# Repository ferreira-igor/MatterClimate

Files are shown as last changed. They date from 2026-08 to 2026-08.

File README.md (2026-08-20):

# MatterClimate






This project transforms an ESP32-based board into a Matter-compatible temperature and humidity sensor using an SHT30 sensor. It provides seamless integration with smart home ecosystems like Alexa, Google Home, and Apple Home through the Matter protocol.

Designed for smart home enthusiasts and developers, this device automatically detects and commissions itself into your Matter network, providing real-time temperature and humidity readings without complex configuration.

The system features automatic commissioning method selection (BLE or WiFi), persistent Matter configuration, robust error recovery with automatic reboot, and LED status indication for easy setup.

## Features

- **Matter Protocol Support**: Compatible with Matter-certified smart home hubs (Alexa, Google Home, Apple Home)
- **Environmental Sensing**: Accurate temperature and humidity readings with SHT30 sensor
- **Automatic Commissioning**: Smart method selection based on hardware capabilities
  - **BLE Commissioning** (ESP32-C3): Standard Matter commissioning via BLE - WiFi credentials provided by the commissioner app
  - **WiFi Commissioning** (Fallback): Captive portal for manual WiFi configuration when BLE is unavailable
- **Smart Reporting**: Configurable thresholds (0.3°C temperature, 2.0% humidity) to minimize network traffic
- **Automatic Recovery**: Detects and handles Matter disconnections, reboots after 60 seconds of lost connectivity
- **LED Status Indication**: Clear visual feedback - LED ON means ready for commissioning, LED OFF means commissioned
- **Automatic Reconnection**: WiFi watchdog for reliable connectivity
- **Error Handling**: Graceful failure recovery with automatic restarts

## Hardware

### Required Components

- ESP32 Development Board (Tested on WeAct Studio ESP32C3, compatible with most ESP32 boards)
- SHT30 Temperature and Humidity Sensor (I2C address 0x45)
- USB Cable for programming and power
- Connecting wires (4-pin I2C connection)

### Supported Boards

The code is tested on the WeAct Studio ESP32C3 but should work on any ESP32-based board with the following:
- Built-in LED (configurable via LED_BUILTIN)
- I2C pins (configurable via pin_i2c_scl and pin_i2c_sda)
- BLE support (for automatic commissioning) or fallback to WiFi commissioning

### Sensor Compatibility

The SHT30 sensor is recommended and tested. Other I2C temperature/humidity sensors may work with minor code modifications:
- SHT31 (compatible)
- SHT35 (compatible)
- AHT10/AHT20 (would require code changes)

## Wiring

The project requires minimal wiring - just the I2C connection for the sensor:

| Component | ESP32 Pin | Description |
|---|---|---|
| SHT30 VCC | 3.3V | Power supply |
| SHT30 GND | GND | Ground |
| SHT30 SCL | GPIO 0 | I2C Clock (WeAct Studio ESP32C3) |
| SHT30 SDA | GPIO 1 | I2C Data (WeAct Studio ESP32C3) |
| Built-in LED | LED_BUILTIN | Status indicator (active LOW) |

**Note**: For other ESP32 boards, adjust the I2C pins in the code:
- pin_i2c_scl: Change to your SCL pin (default: 0)
- pin_i2c_sda: Change to your SDA pin (default: 1)

## Flashing

### Method 1: Pre-compiled Binary

1. Download the latest binary from the Releases page

2. Install esptool:
   ```bash
   pipx install esptool
   ```

3. Using esptool:
   ```bash
   esptool --port /dev/ttyUSB0 erase-flash
   esptool --port /dev/ttyUSB0 write-flash 0x0 MatterClimate.ino.merged.bin
   ```

   Replace /dev/ttyUSB0 with your actual serial port.

### Method 2: Using Arduino IDE

1. **Install ESP32 Core**:
   - Open Arduino IDE
   - Go to File > Preferences
   - Add https://raw.githubusercontent.com/espressif/arduino-esp32/gh-pages/package_esp32_index.json to Additional Boards Manager URLs
   - Go to Tools > Board > Boards Manager
   - Search for ESP32 and install esp32 by Espressif Systems (v3.3.11 or later)

2. **Install Required Libraries**:
   - Open Sketch > Include Library > Manage Libraries
   - Install the following libraries:
     - Adafruit SHT31 by Adafruit (v2.2.2)
     - Matter by Arduino (v1.2.5 or later)
     - WiFiManager by tzapu (v2.0.17) - only required when BLE commissioning is disabled

3. **Configure and Upload**:
   - Open MatterClimate.ino in Arduino IDE
   - Select your ESP32 board: Tools > Board > ESP32 Arduino > [Your Board Model]
   - Select the correct port: Tools > Port > [Your USB Port]
   - Select "Erase All Flash Before Sketch Upload: Enabled"
   - Select "Partition Scheme: Huge APP (3MB No OTA/1MB SPIFFS)"
   - Click Upload (arrow icon) to compile and flash

4. **Monitor Serial Output**:
   - Open Tools > Serial Monitor
   - Set baud rate to 115200
   - Observe startup logs and sensor readings

## Startup

### First Boot and Commissioning

The commissioning method depends on your ESP32 board and the CONFIG_ENABLE_CHIPOBLE flag:

#### Method 1: BLE Commissioning (Recommended - ESP32-C3)

1. **Power the Device**: Connect the ESP32 via USB or power supply
2. **LED Behavior**:
   - LED ON (LOW): Device is NOT commissioned - ready for setup
   - LED OFF (HIGH): Device IS commissioned - operating normally
3. **Commission via Smart Home App**:
   - Open your Matter-compatible app (Alexa, Google Home, Apple Home)
   - Add a new device and scan the QR code displayed in the serial monitor
   - Or enter the manual pairing code shown in the serial output
   - The app will provide WiFi credentials via BLE
   - Wait for commissioning to complete
   - The LED will turn OFF (HIGH) once commissioned

#### Method 2: WiFi Commissioning (Fallback - no BLE)

1. **Power the Device**: Connect the ESP32 via USB or power supply
2. **Connect to Captive Portal**:
   - The device creates a WiFi access point (usually named MatterClimate or similar)
   - Connect your phone or computer to this network
3. **Configure WiFi**:
   - Open a web browser and navigate to the captive portal (usually 192.168.4.1)
   - Enter your WiFi credentials
   - Device will connect to your WiFi network
4. **Commission via Matter**:
   - Use your Matter-compatible app to add the device
   - Scan the QR code or enter the manual pairing code shown in the serial monitor
   - The device will be commissioned to your Matter hub

### Commissioning Information

After startup, the serial monitor will display:
- Manual pairing code (numeric code for manual entry)
- QR code URL (for scanning with smart home apps)

Use this information to commission the device to your Matter hub.

### LED Status Indicator

| LED State | Pin State | Meaning |
|---|---|---|
| ON (LOW) | 0 | Device NOT commissioned - ready for setup |
| OFF (HIGH) | 1 | Device IS commissioned - operating normally |

## Configuration

### Sensor Reporting Thresholds

The device uses smart reporting to minimize network traffic:

- **Temperature**: Reports when changes exceed 0.3°C
- **Humidity**: Reports when changes exceed 2.0%

These thresholds can be adjusted in the code:
- temperature_diff: Adjust as needed (default: 0.3f)
- humidity_diff: Adjust as needed (default: 2.0f)

### Timing Parameters

| Parameter | Default | Description |
|---|---|---|
| Sensors Read Interval | 1 second | How often sensor is read |
| Matter Check Interval | 15 seconds | How often connection is verified |
| Matter Timeout | 3 minutes | Max disconnection time before reboot |
| WiFi Manager Timeout | 3 minutes | Captive portal timeout (WiFi method) |

## Notes

### Important Considerations

- **Matter Compatibility**: Ensure your smart home hub supports Matter (most modern hubs do)
- **Network Requirements**: Device must be on the same network as your Matter hub
- **BLE Commissioning**: Requires BLE support on the ESP32 (ESP32-C3 has built-in BLE)
- **Power Requirements**: ESP32 boards typically require 5V via USB or 3.3V from a regulated power supply
- **Sensor Placement**: For accurate readings, place the sensor away from heat sources and in open air

### Performance and Limitations

- **Reading Frequency**: Sensor is read every 1 second - sufficient for most environmental monitoring applications
- **Reporting Frequency**: Reports are sent only when thresholds are exceeded, reducing network traffic
- **Connection Recovery**: Automatic reboot after 60 seconds of disconnection ensures reliability
- **Memory Usage**: Matter library requires significant flash - use appropriate partition scheme

### Security Considerations

- **Matter Security**: Uses Matter's built-in security and encryption
- **WiFi Credentials**: Stored in ESP32's non-volatile storage
- **BLE Commissioning**: Secure pairing using Matter's standard commissioning process
- **WiFi Manager**: Only active during setup, not during normal operation

### Troubleshooting

| Issue | Solution |
|---|---|
| Sensor not initializing | Check wiring; verify I2C pins; ensure sensor is powered |
| LED stays ON continuously | Device is not commissioned - complete commissioning process |
| Commissioning fails | Verify Matter hub supports the device; check network connectivity |
| No sensor readings | Check I2C address (0x45); verify SHT30 library installed |
| Device doesn't appear in Matter app | Ensure device is on the same network; reboot device and try again |
| Frequent disconnections | Check WiFi signal strength; adjust device placement |
| Serial output shows no QR code | Ensure partition scheme has enough space for Matter library |

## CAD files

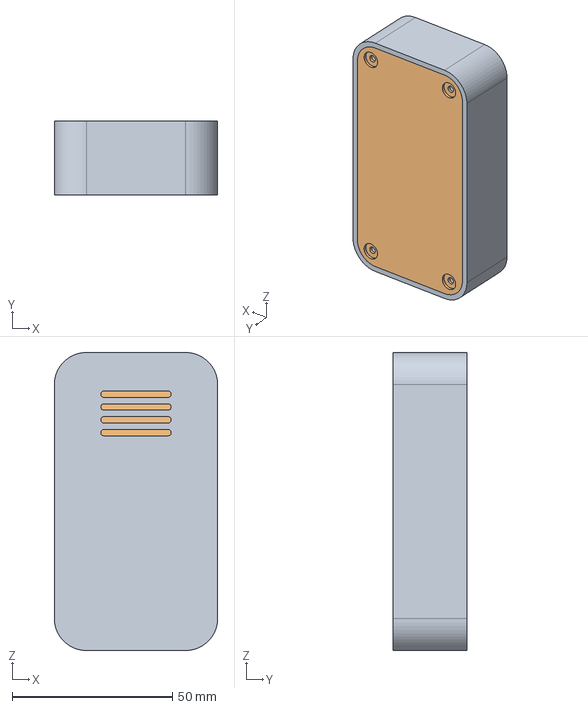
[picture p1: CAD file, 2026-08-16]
MatterClimate.FCStd
51.0 x 23.0 x 93.0 mm
Lid

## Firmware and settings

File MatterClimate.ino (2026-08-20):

/**
 * @file MatterClimate.ino
 * @brief Matter-compatible Temperature and Humidity Sensor
 * 
 * This firmware implements a Matter-compatible environmental sensor using
 * an ESP32 with an SHT30 temperature/humidity sensor. It provides:
 * - Matter protocol support for smart home integration
 * - Temperature and humidity sensing with SHT30
 * - Automatic commissioning method selection (BLE or WiFi)
 * - Automatic reconnection and error recovery
 * - LED status indication (active LOW)
 * 
 * @author Igor Ferreira
 * @version 1.0
 * @date 2026
 * 
 * @hardware WeAct Studio ESP32C3 (tested)
 * @sensor Adafruit SHT30 (I2C address 0x45)
 * @toolchain Arduino IDE 2.3.10
 * @core ESP32 Arduino Core 3.3.11
 * 
 * @note Commissioning Method Selection:
 *       - ESP32-C3: Uses BLE commissioning (CONFIG_ENABLE_CHIPOBLE enabled)
 *         WiFi credentials are provided by the Matter commissioner (Alexa,
 *         Google Home, Apple Home) during commissioning via BLE
 * 
 *       - ESP32 (without BLE) or when CONFIG_ENABLE_CHIPOBLE is disabled:
 *         Uses WiFi commissioning via WiFiManager captive portal
 *         User manually configures WiFi credentials through a web interface
 * 
 *       The code automatically adapts to the available commissioning method
 *       based on the CONFIG_ENABLE_CHIPOBLE compilation flag.
 * 
 * @note LED Behavior (Active LOW - typical for ESP32 boards):
 *       - LED ON (LOW): Device is NOT commissioned - ready for setup
 *       - LED OFF (HIGH): Device IS commissioned - operating normally
 * 
 * @note The SHT30 sensor communicates via I2C on pins 0 (SCL) and 1 (SDA)
 *       as defined for the WeAct Studio ESP32C3 board. Adjust pins for
 *       other ESP32 boards if needed.
 */

#include <Arduino.h>

#include <Wire.h>
#include <Adafruit_SHT31.h>  // https://github.com/adafruit/Adafruit_SHT31/releases/tag/v2.2.2

#include <Matter.h>

//=============================================================================
// Conditional WiFi Configuration
//=============================================================================

/**
 * @brief WiFiManager is included only when BLE commissioning is disabled
 * 
 * The commissioning method is determined at compile time:
 * 
 * 1. BLE Commissioning (CONFIG_ENABLE_CHIPOBLE = 1):
 *    - Used by ESP32-C3 and other boards with BLE support
 *    - WiFi credentials are provided by the Matter commissioner app
 *      (Alexa, Google Home, Apple Home) via BLE
 *    - WiFiManager is NOT used
 *    - This is the recommended method for most ESP32 boards
 * 
 * 2. WiFi Commissioning (CONFIG_ENABLE_CHIPOBLE = 0):
 *    - Used as fallback for boards without BLE or for debugging
 *    - ESP32 creates a captive portal WiFi network
 *    - User connects and configures WiFi via web interface
 *    - WiFiManager handles the configuration process
 * 
 * The conditional compilation ensures the code works on both BLE-capable
 * and non-BLE boards without modification.
 */
#if !CONFIG_ENABLE_CHIPOBLE
#include <WiFi.h>
#include <WiFiManager.h>  // https://github.com/tzapu/WiFiManager/releases/tag/v2.0.17

/** @brief WiFiManager instance for captive portal (BLE commissioning disabled) */
WiFiManager wm;
#endif

//=============================================================================
// Hardware Configuration Constants
//=============================================================================

/** @brief I2C SCL pin (GPIO 0 - adjust for other ESP32 boards) */
constexpr uint8_t pin_i2c_scl = 0;

/** @brief I2C SDA pin (GPIO 1 - adjust for other ESP32 boards) */
constexpr uint8_t pin_i2c_sda = 1;

/**
 * @brief Built-in LED pin for status indication (Active LOW)
 * 
 * The LED is connected between VCC and the GPIO pin (common on ESP32 boards).
 * - LOW = LED ON
 * - HIGH = LED OFF
 */
constexpr uint8_t pin_led = LED_BUILTIN;

//=============================================================================
// Sensor Data Variables
//=============================================================================

/** @brief Current temperature reading in Celsius */
float current_temperature = 0.0f;

/** @brief Last temperature value reported to Matter */
float reported_temperature = 0.0f;

/**
 * @brief Temperature change threshold for reporting
 * 
 * Only report temperature changes greater than this value (0.3°C)
 * to avoid excessive Matter updates.
 */
const float temperature_diff = 0.3f;

/** @brief Current humidity reading in percentage */
float current_humidity = 0.0f;

/** @brief Last humidity value reported to Matter */
float reported_humidity = 0.0f;

/**
 * @brief Humidity change threshold for reporting
 * 
 * Only report humidity changes greater than this value (2.0%)
 * to avoid excessive Matter updates.
 */
const float humidity_diff = 2.0f;

//=============================================================================
// Timing Constants
//=============================================================================

/** @brief Interval between sensor readings */
const uint32_t sensors_read_interval = 1000;

/** @brief Interval for Matter connection checks */
const uint32_t matter_check_interval = 15000;

/** @brief Maximum time without Matter connection before reboot */
const uint32_t matter_timeout = 180000;

/**
 * @brief Counter for consecutive Matter disconnections
 * 
 * Incremented when device is commissioned but not connected.
 * Reset to 0 when connection is restored.
 */
uint8_t matter_disconnect_counter = 0;

/** @brief Timestamp of last sensor reading */
uint32_t last_sensors_read = 0;

/** @brief Timestamp of last Matter connection check */
uint32_t last_matter_check = 0;

//=============================================================================
// Sensor Initialization
//=============================================================================

/** @brief I2C address for SHT30 sensor (0x45) */
constexpr uint8_t sht30_addr = 0x45;

/** @brief SHT30 sensor instance */
Adafruit_SHT31 sht31 = Adafruit_SHT31();

//=============================================================================
// Matter Endpoints
//=============================================================================

/**
 * @brief Matter Temperature Sensor endpoint
 * 
 * Represents the temperature sensor as a Matter device.
 * Provides standard Matter temperature measurement cluster.
 */
MatterTemperatureSensor temperatureSensor;

/**
 * @brief Matter Humidity Sensor endpoint
 * 
 * Represents the humidity sensor as a Matter device.
 * Provides standard Matter humidity measurement cluster.
 */
MatterHumiditySensor humiditySensor;

//=============================================================================
// Sensor Reading Functions
//=============================================================================

/**
 * @brief Read data from SHT30 sensor
 * 
 * Reads temperature and humidity from the SHT30 sensor.
 * Updates global current_temperature and current_humidity variables.
 * Validates readings (checks for NaN) and logs errors if readings fail.
 * 
 * @note This function is called every 1 second (sensors_read_interval)
 * 
 * @warning SHT30 may return NaN if sensor is disconnected or I2C fails.
 */
void readSensors() {

  // Read temperature (Celsius)
  float t = sht31.readTemperature();

  if (!isnan(t)) {
    current_temperature = t;
    Serial.print("Temperature: ");
    Serial.print(current_temperature);
    Serial.println("°C");
  } else {
    Serial.println("Error reading temperature!");
  }

  // Read humidity (percentage)
  float h = sht31.readHumidity();

  if (!isnan(h)) {
    current_humidity = h;
    Serial.print("Humidity: ");
    Serial.print(current_humidity);
    Serial.println("%");
  } else {
    Serial.println("Error reading humidity!");
  }
}

//=============================================================================
// Matter Update Functions
//=============================================================================

/**
 * @brief Update Matter endpoints with new sensor data
 * 
 * Checks if the device is commissioned and connected to a Matter hub.
 * Compares current readings with last reported values and updates
 * Matter endpoints only when changes exceed configured thresholds.
 * 
 * @note Temperature threshold: 0.3°C
 * @note Humidity threshold: 2.0%
 * 
 * This prevents unnecessary network traffic and Matter updates
 * when sensor values fluctuate minimally.
 */
void updateMatter() {

  // Only update if device is commissioned
  if (Matter.isDeviceCommissioned()) {

    // Update temperature if change exceeds threshold
    if (fabsf(current_temperature - reported_temperature) >= temperature_diff) {
      temperatureSensor.setTemperature(current_temperature);
      reported_temperature = current_temperature;
    }

    // Update humidity if change exceeds threshold
    if (fabsf(current_humidity - reported_humidity) >= humidity_diff) {
      humiditySensor.setHumidity(current_humidity);
      reported_humidity = current_humidity;
    }
  }
}

//=============================================================================
// Matter Connection Management
//=============================================================================

/**
 * @brief Check Matter connection status and handle disconnections
 * 
 * Monitors the Matter connection state and implements a recovery strategy:
 * 1. Updates LED status based on commissioning state (Active LOW)
 * 2. Tracks disconnection duration
 * 3. Automatically decommissions and reboots after timeout
 * 
 * LED Behavior (Active LOW - LED ON when pin is LOW):
 * - LED ON (LOW):  Device is NOT commissioned - ready for commissioning
 * - LED OFF (HIGH): Device IS commissioned - operating normally
 * 
 * This provides clear visual feedback:
 * - Blinking/ON LED indicates device needs to be set up
 * - OFF LED indicates device is already in your smart home
 * 
 * Recovery Strategy:
 * - Counts consecutive check cycles where device is commissioned but disconnected
 * - If disconnection persists for matter_timeout (60s), decommission and reboot
 * - This forces the device to be re-added to the Matter network
 * 
 * @note Check interval is defined by matter_check_interval
 * @note matter_disconnect_counter increments each check cycle when disconnected
 * @note Counter resets to 0 when connection is restored
 */
void checkMatter() {

  // Update LED based on commission status (Active LOW)
  // LED ON (LOW)  = Not commissioned - ready for setup
  // LED OFF (HIGH) = Commissioned - operating normally
  if (!Matter.isDeviceCommissioned()) {
    digitalWrite(pin_led, LOW);  // LED ON - waiting for commissioning
  } else {
    digitalWrite(pin_led, HIGH);  // LED OFF - commissioned and running
  }

  // Detect disconnection scenario:
  // Device is commissioned (known to hub) but not connected (communication lost)
  if (Matter.isDeviceCommissioned() != Matter.isDeviceConnected()) {
    matter_disconnect_counter++;
    Serial.println("Device disconnected!");

    // If disconnected for longer than matter_timeout
    if (matter_disconnect_counter >= (matter_timeout / matter_check_interval)) {
      Serial.println("The connection was lost! Decommissioning and rebooting...");

      // Decommission the device (removes it from the Matter network)
      Matter.decommission();
      matter_disconnect_counter = 0;

      // Allow time for decommissioning to complete
      delay(1000);

      // Reboot to start fresh
      ESP.restart();
    }
  } else {
    // Connection restored or still connected - reset counter
    matter_disconnect_counter = 0;
  }
}

//=============================================================================
// Setup Function
//=============================================================================

/**
 * @brief Arduino setup function
 * 
 * Initializes the system in the following order:
 * 1. Hardware initialization (pins, LED, serial, I2C)
 * 2. SHT30 sensor initialization
 * 3. WiFi configuration (method depends on CONFIG_ENABLE_CHIPOBLE)
 * 4. Matter endpoint initialization (temperature and humidity)
 * 5. Matter protocol initialization
 * 6. Display commissioning information (pairing code, QR code)
 * 
 * WiFi Configuration Methods:
 * 
 * A) BLE Commissioning (CONFIG_ENABLE_CHIPOBLE = 1):
 *    - Used by ESP32-C3 and BLE-capable boards
 *    - WiFi credentials are NOT defined in code
 *    - The Matter commissioner (Alexa, Google Home, Apple Home) app
 *      provides WiFi credentials during commissioning via BLE
 *    - No user interaction required for WiFi setup
 *    - This is the standard Matter commissioning flow
 * 
 * B) WiFi Commissioning (CONFIG_ENABLE_CHIPOBLE = 0):
 *    - Used by boards without BLE or for debugging
 *    - ESP32 creates a captive portal WiFi network
 *    - User connects to the ESP32's AP and configures WiFi via web
 *    - WiFiManager handles the configuration process
 *    - Useful for testing or when BLE is not available
 * 
 * The conditional compilation allows the same code to work on
 * different ESP32 boards without modification.
 * 
 * LED Behavior (Active LOW - LED ON when pin is LOW):
 * - LED ON (LOW) during initialization
 * - After setup, LED state is managed by checkMatter():
 *   * LED ON (LOW)  = Not commissioned - ready for setup
 *   * LED OFF (HIGH) = Commissioned - operating normally
 * 
 * @note I2C pins are configured for WeAct Studio ESP32C3 (pins 0 and 1)
 *       Adjust for other ESP32 boards if needed
 * 
 * @warning If SHT30 initialization fails, an error message is printed but setup continues
 * @warning If WiFi commissioning fails (WiFiManager mode), the device reboots
 */
void setup() {

  //-----------------------------------------------------------------------
  // 1. Hardware Initialization
  //-----------------------------------------------------------------------

  pinMode(pin_led, OUTPUT);

  // LED ON during initialization (Active LOW)
  digitalWrite(pin_led, LOW);

  Serial.begin(115200);

  // Allow time for serial to initialize
  delay(1000);

  //-----------------------------------------------------------------------
  // 2. SHT30 Sensor Initialization
  //-----------------------------------------------------------------------

  Wire.begin(pin_i2c_sda, pin_i2c_scl);

  while (!sht31.begin(sht30_addr)) {
    Serial.println("Error initializing SHT30 sensor. Check your wiring!");
    delay(1000);
  }

  //-----------------------------------------------------------------------
  // 3. WiFi Configuration (Conditional based on commissioning method)
  //-----------------------------------------------------------------------

  /**
   * WiFi configuration method is selected at compile time:
   * 
   * - If CONFIG_ENABLE_CHIPOBLE is defined (default for ESP32-C3):
   *   BLE commissioning is used. WiFi credentials are provided by the
   *   Matter commissioner app during commissioning. No manual setup needed.
   * 
   * - If CONFIG_ENABLE_CHIPOBLE is NOT defined (fallback):
   *   WiFiManager captive portal is used. User manually configures WiFi
   *   credentials through a web interface. Useful for boards without BLE
   *   or for debugging purposes.
   * 
   * This design ensures compatibility with both BLE-capable and non-BLE
   * ESP32 boards without code changes.
   */
#if !CONFIG_ENABLE_CHIPOBLE
  // WiFi Commissioning Mode (Captive Portal)
  std::vector<const char *> menu = { "wifi", "restart", "exit" };
  wm.setMenu(menu);
  wm.setConfigPortalTimeout(180);  // 3 minutes timeout
  wm.setConnectTimeout(30);        // 30 seconds connection timeout

  if (!wm.autoConnect()) {
    Serial.println("Could not connect to WiFi! Rebooting...");
    delay(1000);
    ESP.restart();
  }
#endif

  //-----------------------------------------------------------------------
  // 4. Matter Endpoint Initialization
  //-----------------------------------------------------------------------

  if (!temperatureSensor.begin()) {
    Serial.println("Error initializing temperature endpoint!");
  }

  if (!humiditySensor.begin()) {
    Serial.println("Error initializing humidity endpoint!");
  }

  //-----------------------------------------------------------------------
  // 5. Matter Protocol Initialization
  //-----------------------------------------------------------------------

  Matter.begin();

  //-----------------------------------------------------------------------
  // 6. Commissioning Information
  //-----------------------------------------------------------------------

  if (!Matter.isDeviceCommissioned()) {
    Serial.println("Matter Node is not commissioned yet.");
    Serial.println("Initiate the device discovery in your Matter environment.");
    Serial.println("Commission it to your Matter hub with the manual pairing code or QR code");
    Serial.print("Manual pairing code: ");
    Serial.println(Matter.getManualPairingCode().c_str());
    Serial.print("QR code URL: ");
    Serial.println(Matter.getOnboardingQRCodeUrl().c_str());
  }
}

//=============================================================================
// Loop Function
//=============================================================================

/**
 * @brief Arduino main loop
 * 
 * Manages periodic tasks using non-blocking timers:
 * 1. Sensor Reading:
 *    - Reads temperature and humidity from SHT30
 *    - Updates Matter endpoints if changes exceed thresholds
 * 
 * 2. Matter Connection Check:
 *    - Monitors commission and connection status
 *    - Handles disconnection recovery
 *    - Updates LED status (Active LOW)
 * 
 * @note Uses millis() for timing instead of delay() to keep loop non-blocking
 * @note Both tasks run independently at their configured intervals
 */
void loop() {

  uint32_t current_time = millis();

  // Task 1: Read sensors
  if (current_time - last_sensors_read >= sensors_read_interval) {
    last_sensors_read = current_time;
    readSensors();
    updateMatter();
  }

  // Task 2: Check Matter connection
  if (current_time - last_matter_check >= matter_check_interval) {
    last_matter_check = current_time;
    checkMatter();
  }
}
